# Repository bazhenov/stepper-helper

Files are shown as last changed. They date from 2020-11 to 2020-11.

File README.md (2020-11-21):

# Stepper motor tester

Simple stepper motor tester designed around stuff I've had laying around: standart 0.1" perf board, 555 timer, 1117 voltage regulator and some passives.

Oscillator design is 50% duty cycle astable 555 timer.

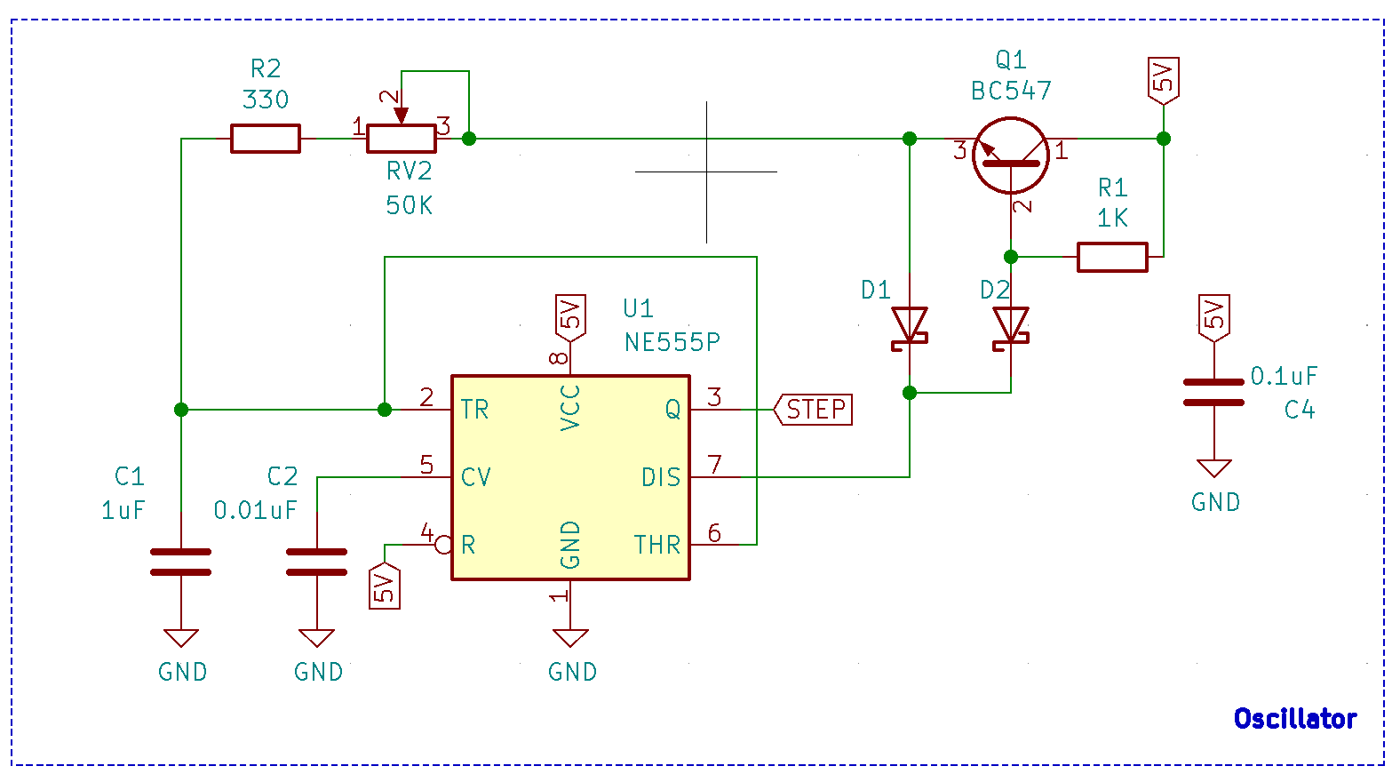
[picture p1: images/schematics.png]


PCB design has mix of SMD and TH components simply because that is what I have at the moment. It turns out you can mix those types of components quite easily on perfboard :) Ratsnet is showing flywires, tracks are created using solder bridges.

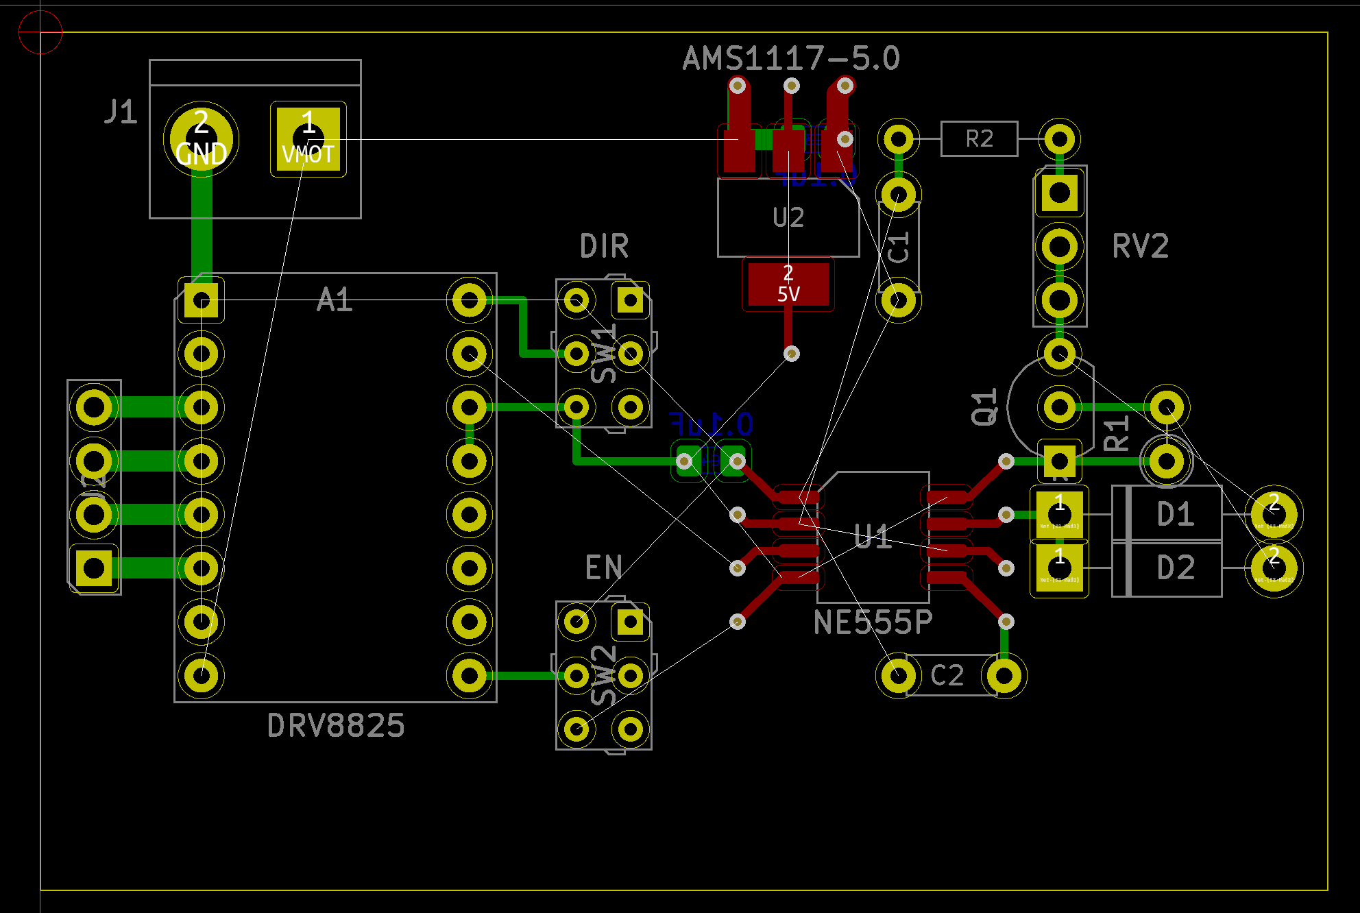
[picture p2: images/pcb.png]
PCB


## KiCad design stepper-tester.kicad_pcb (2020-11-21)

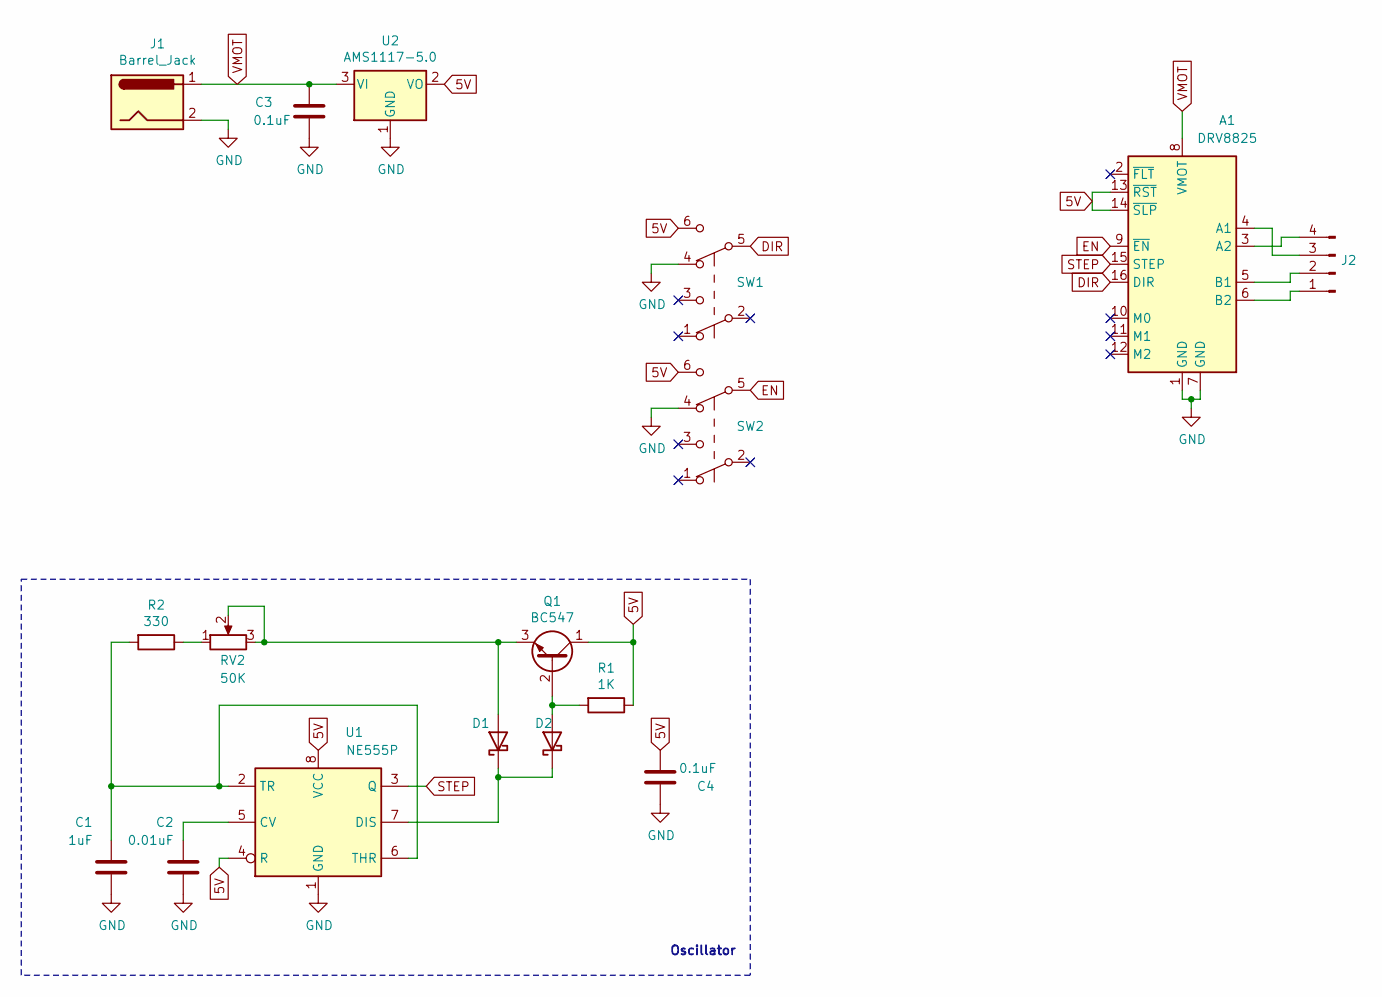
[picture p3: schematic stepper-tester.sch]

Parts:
A1: DRV8825; Pololu_Breakout-16_15.2x20.3mm
C1: 1uF; C_Disc_D4.3mm_W1.9mm_P5.00mm
C2: 0.01uF; C_Disc_D4.3mm_W1.9mm_P5.00mm
C3, C4: 0.1uF; C_0805_2012Metric_Pad1.18x1.45mm_HandSolder
D1, D2: 1N5817; D_DO-41_SOD81_P10.16mm_Horizontal
J1: Barrel_Jack; TerminalBlock_bornier-2_P5.08mm
J2: Conn_01x04_Male; PinSocket_1x04_P2.54mm_Vertical
Q1: BC547; TO-92L_Inline_Wide
R1: 1K; R_Axial_DIN0207_L6.3mm_D2.5mm_P2.54mm_Vertical
R2: 330; R_Axial_DIN0204_L3.6mm_D1.6mm_P7.62mm_Horizontal
RV2: 50K; PinHeader_1x03_P2.54mm_Vertical
SW1, SW2: SW_Push_DPDT; SW_NKK_GW12LJP
U1: NE555P; SO-8_5.3x6.2mm_P1.27mm
U2: AMS1117-5.0; SOT-223-3_TabPin2

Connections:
5V: A1.13 (~RST), A1.14 (~SLP), C4.1, Q1.1 (C), R1.1, SW1.6 (C), SW2.6 (C), U1.4 (R), U1.8 (VCC), U2.2 (VO)
DIR: A1.16 (DIR), SW1.5 (B)
EN: A1.9 (~EN), SW2.5 (B)
GND: A1.1 (GND), A1.7 (GND), C1.1, C2.1, C3.1, C4.2, J1.2, SW1.4 (A), SW2.4 (A), U1.1 (GND), U2.1 (GND)
unnamed: A1.3 (A2), J2.4
unnamed: A1.4 (A1), J2.3
unnamed: A1.5 (B1), J2.2
unnamed: A1.6 (B2), J2.1
unnamed: C1.2, R2.2, U1.2 (TR), U1.6 (THR)
unnamed: C2.2, U1.5 (CV)
unnamed: D1.1 (K), D2.1 (K), U1.7 (DIS)
unnamed: D1.2 (A), Q1.3 (E), RV2.2, RV2.3
unnamed: D2.2 (A), Q1.2 (B), R1.2
unnamed: R2.1, RV2.1
STEP: A1.15 (STEP), U1.3 (Q)
VMOT: A1.8 (VMOT), C3.2, J1.1, U2.3 (VI)

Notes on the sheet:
Oscillator

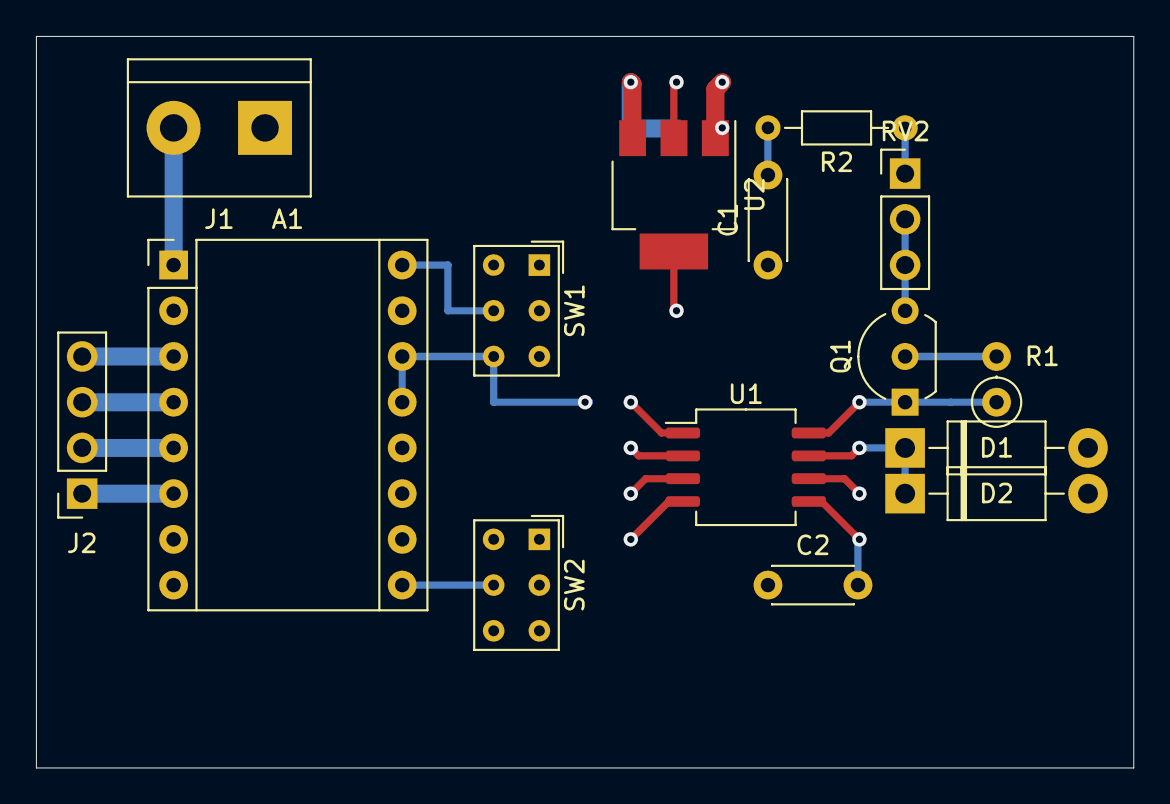
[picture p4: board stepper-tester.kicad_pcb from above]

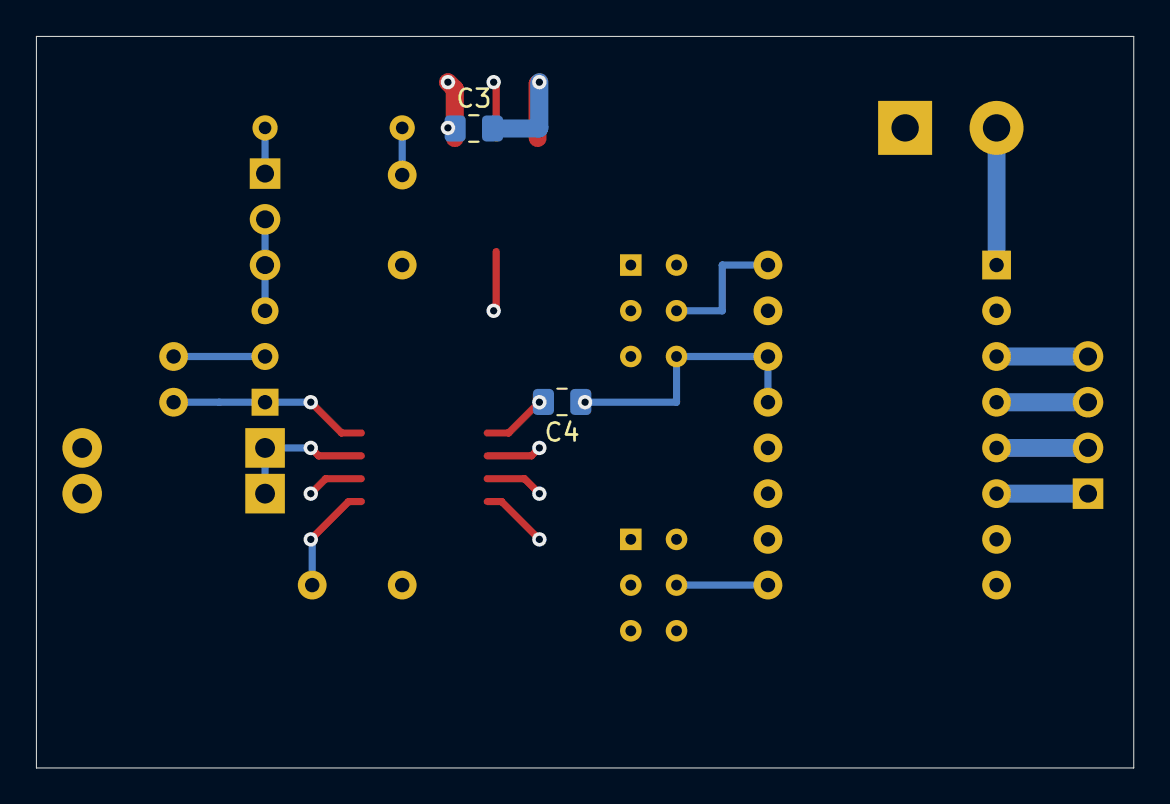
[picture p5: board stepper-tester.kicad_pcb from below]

Board: 2 copper layers, 61.0 x 40.6 mm, 17 parts (2 on the bottom side), 16 nets.

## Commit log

2020-07-29 Kicad update
    [stepper-tester.sch]
2020-07-30 Update schematics
    [stepper-tester.sch]
2020-08-01 NE555 schematic verified
    [stepper-tester.sch]
2020-08-02 All footprints associated
    [stepper-tester.sch]
2020-08-04 PCB cleanup
    [stepper-tester.kicad_pcb]
2020-08-09 new layout
    [stepper-tester.kicad_pcb]
2020-10-06 50% duty cycle 555 schematics
    [stepper-tester.sch]
2020-10-07 PCB WIP
    [stepper-tester.kicad_pcb, stepper-tester.sch]
2020-11-21 Add readme
    [stepper-tester.kicad_pcb]
